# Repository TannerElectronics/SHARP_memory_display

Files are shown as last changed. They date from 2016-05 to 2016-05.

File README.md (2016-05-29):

# SHARP_memory_display
SPI breakout board example code for the Arduino platform

This example sketch is based on and requires two libraries from Adafruit. 

You will need to have installed the Adafruit GFX library from 
https://github.com/adafruit/Adafruit-GFX-Library 

As well as her SHARP library from 
https://github.com/adafruit/Adafruit_SHARP_Memory_Display

Images of front and back of module.

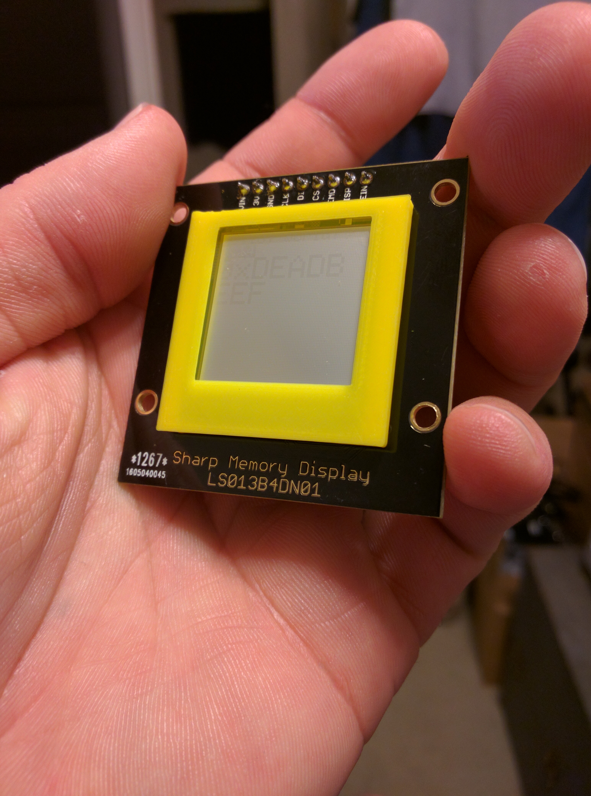
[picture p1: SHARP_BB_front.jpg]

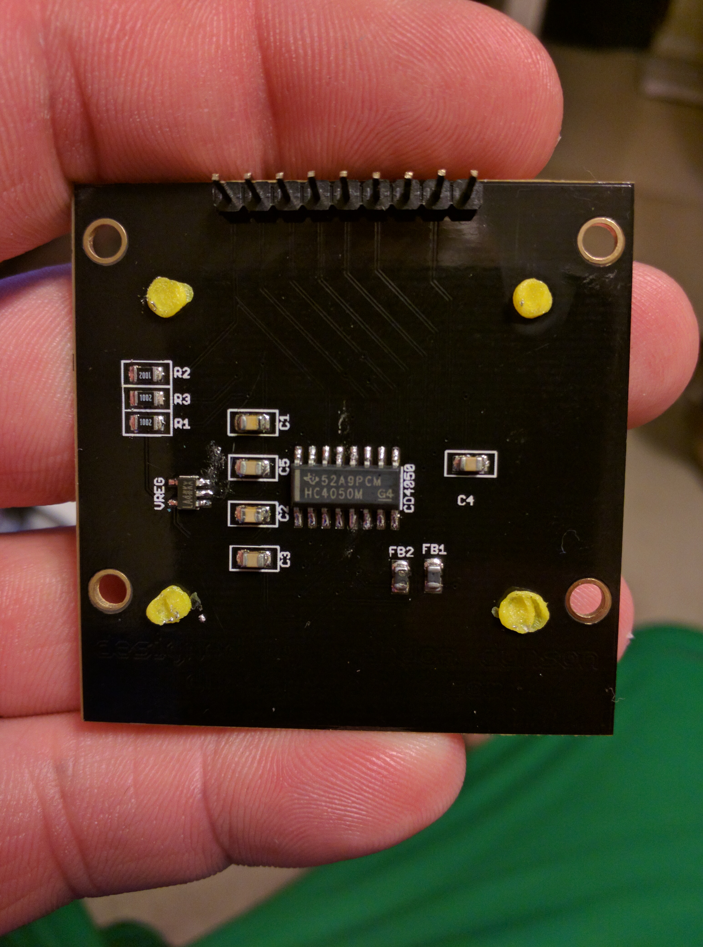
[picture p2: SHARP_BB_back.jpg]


Click image below to follow link to YouTube demo.

<a href="http://www.youtube.com/watch?feature=player_embedded&v=JAfuR7puMNo
" target="_blank">Short demo video</a>

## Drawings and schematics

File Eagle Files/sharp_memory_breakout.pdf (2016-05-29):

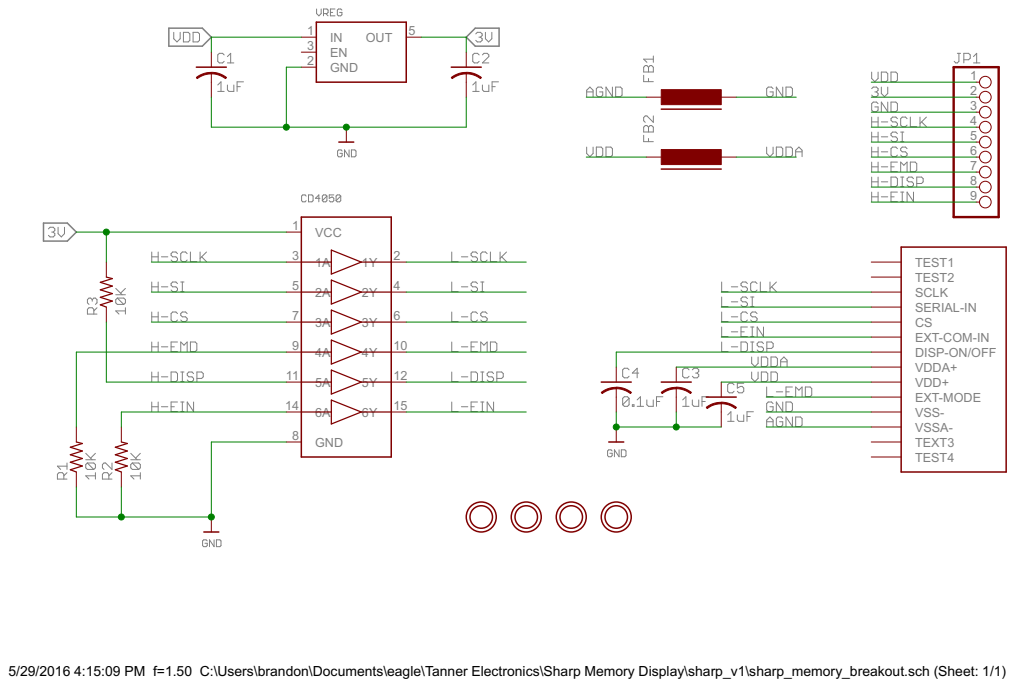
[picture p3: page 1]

5/29/2016 4:15:09 PM f=1.50 C:\Users\brandon\Documents\eagle\Tanner Electronics\Sharp Memory Display\sharp_v1\sharp_memory_breakout.sch (Sheet: 1/1)

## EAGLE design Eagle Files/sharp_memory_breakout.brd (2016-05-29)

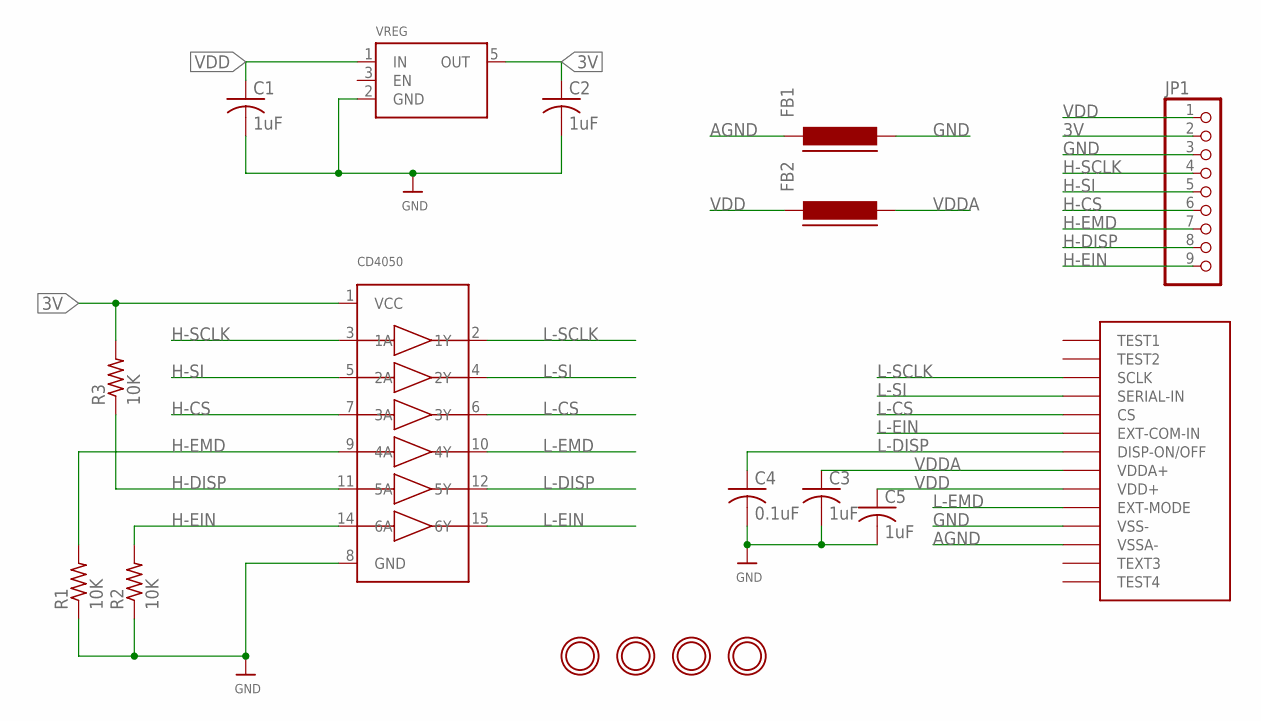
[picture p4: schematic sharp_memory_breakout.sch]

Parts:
C1, C2, C3, C5: 1uF; C0805K
C4: 0.1uF; C0805K
CD4050: 74HC4050D; SOIC16
FB1, FB2: FERRITE-0603; FB603
JP1: PINHD-1X9; 1X09-BIG
R1, R2, R3: 10K; R0805
U$1: SHARP-MEMORY
U$2, U$3, U$4, U$5: MOUNTINGHOLE3.0THIN; MOUNTINGHOLE_3.0_PLATEDTHIN
VREG: ADP121; SOT23-5

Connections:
3V: C2.1, CD4050.1 (VCC), JP1.2, R3.2, VREG.5 (OUT)
AGND: FB1.1, U$1.P$12 (VSSA-)
GND: C1.2, C2.2, C3.2, C4.2, C5.2, CD4050.8 (GND), FB1.2, JP1.3, R1.1, R2.1, U$1.P$11 (VSS-), VREG.2 (GND)
H-CS: CD4050.7 (3A), JP1.6
H-DISP: CD4050.11 (5A), JP1.8, R3.1
H-EIN: CD4050.14 (6A), JP1.9, R2.2
H-EMD: CD4050.9 (4A), JP1.7, R1.2
H-SCLK: CD4050.3 (1A), JP1.4
H-SI: CD4050.5 (2A), JP1.5
L-CS: CD4050.6 (3Y), U$1.P$5 (CS)
L-DISP: C4.1, CD4050.12 (5Y), U$1.P$7 (DISP-ON/OFF)
L-EIN: CD4050.15 (6Y), U$1.P$6 (EXT-COM-IN)
L-EMD: CD4050.10 (4Y), U$1.P$10 (EXT-MODE)
L-SCLK: CD4050.2 (1Y), U$1.P$3 (SCLK)
L-SI: CD4050.4 (2Y), U$1.P$4 (SERIAL-IN)
VDD: C1.1, C5.1, FB2.1, JP1.1, U$1.P$9 (VDD+), VREG.1 (IN)
VDDA: C3.1, FB2.2, U$1.P$8 (VDDA+)

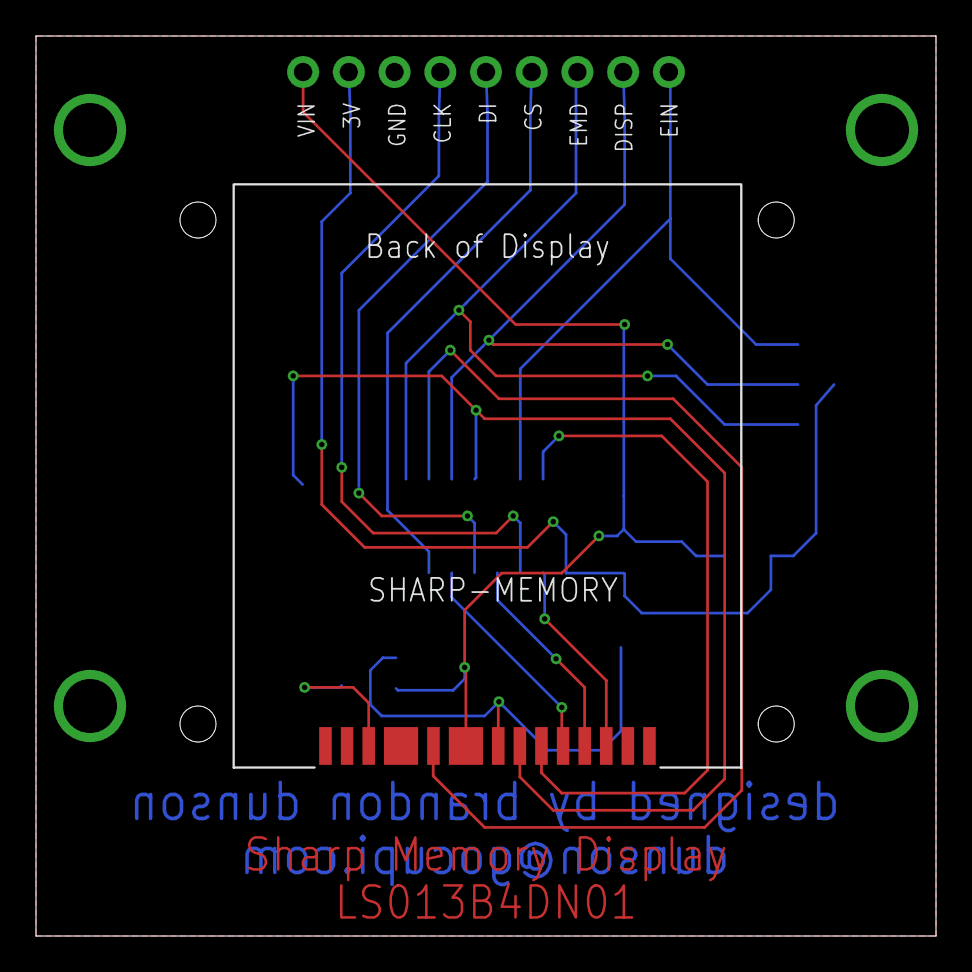
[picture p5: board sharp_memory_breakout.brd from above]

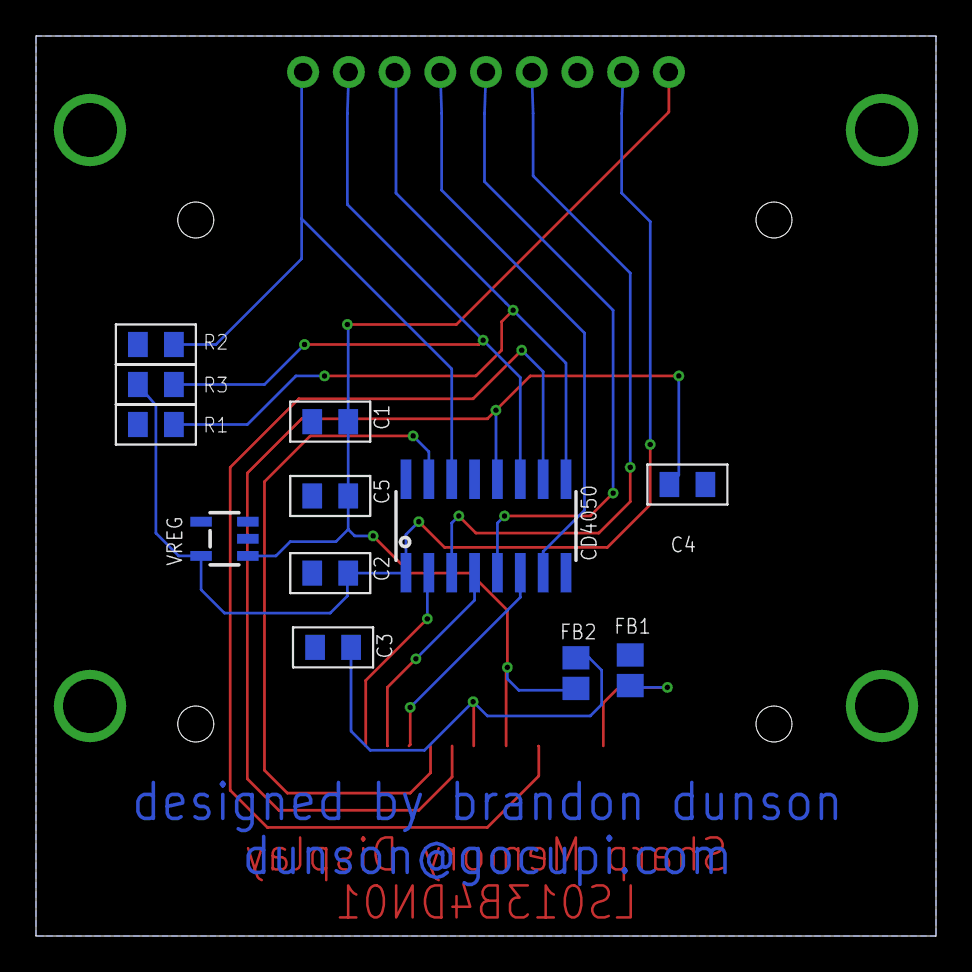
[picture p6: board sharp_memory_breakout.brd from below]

Board: 2 copper layers, 50.0 x 50.0 mm, 18 parts (12 on the bottom side), 17 nets.

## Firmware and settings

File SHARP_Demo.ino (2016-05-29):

/*
 * Written by Brandon Dunson for Tanner Electronics on May 29th, 2016
 * based on libraries and demos from Adafruit.
 * 
 * check out Adafruit at http://adafruit.com and Tanner's at http://tannerelectronics.com
 * 
 */

// Libraries we lean on
#include <Adafruit_GFX.h>
#include <Adafruit_SharpMem.h>

// Fonts used in the demo
#include <Fonts/FreeSansBold9pt7b.h>
#include <Fonts/FreeSansBoldOblique12pt7b.h>

// any pins can be used
#define CLK 10
#define DI 11
#define CS 12

Adafruit_SharpMem display(CLK, DI, CS);

#define BLACK 0
#define WHITE 1

int count = 0;

void setup(void) 
{
  // start & clear the display
  display.begin();
  display.clearDisplay();

  // Adafruit's module is setup 180 degrees different,
  // this will fix the problem.
  display.setRotation(0);

  // First line of text
  display.setTextSize(1);
  display.setTextColor(BLACK);
  display.setCursor(25,1);
  display.println("Tanner's");

  // Second to last line of txt
  display.setCursor(10,75);
  display.println("Hello, world!");

  // Last line of text
  display.setCursor(9,85);
  display.setTextColor(WHITE, BLACK); // 'inverted' text
  display.println(" demo sketch ");
  
  // Third line of text
  display.setTextColor(BLACK);
  display.setFont(&FreeSansBold9pt7b);
  display.setCursor(12,50);
  display.println("Memory");

  // Fourth line of text
  display.setCursor(15,65);
  display.println("Display");  
  
  display.refresh();
}

void loop(void) 
{
  // Incriment variable 'count' at start of each loop
  count++; 

  // If variable 'count' is odd
  // Draw 'SHARP' black (mirror) on white
  if(count%2)
    {
      display.fillRect(0,10,96,24,WHITE);  
      display.setFont(&FreeSansBoldOblique12pt7b);
      display.setCursor(4,30);
      display.setTextColor(BLACK);
      display.println("SHARP");

  // If variable count is even    
  // Draw 'SHARP' white on black (mirror)
    }else{

      display.fillRect(0,10,96,24,BLACK);
      display.setFont(&FreeSansBoldOblique12pt7b);
      display.setCursor(4,30);
      display.setTextColor(WHITE);
      display.println("SHARP");
    
  }
  
  // Display has to be updated to retain visible data
  display.refresh();
  delay(750);
}

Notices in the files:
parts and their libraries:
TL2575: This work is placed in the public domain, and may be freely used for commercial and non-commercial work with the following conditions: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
